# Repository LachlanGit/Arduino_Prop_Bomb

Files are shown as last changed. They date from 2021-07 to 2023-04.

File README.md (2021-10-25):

# Arduino Prop Bomb
Prop bomb for use in Airsoft/Gel ball/Nerf games

[Check out the video here](https://youtu.be/Dwf5lzY_378)

Submit issues via the issues tab. Contact me at lachlan.github@outlook.com

## Electronics parts list: 
(It may be possible to use alternative parts, however, the code will have to be customised for them)
- Arduino Mega 2560
- 12 button keypad (0-9, *, #)
- 128 * 64 3-wire SPI LCD display (I used [this](https://www.digikey.com.au/product-detail/en/dfrobot/DFR0091/DFR0091-ND/7597123) one)
- Red and green buttons either with built in LED's or separate LED's (Make sure to use the appropriate resistor for your LED's)
- 3 position 2 pole keyswitch if using for power and to enter config mode **or** 2 position 1 pole switch if just for config mode (Use a separate switch for power)
- Square wave buzzer
- 7 to 12 volt power supply for Arduino (in my case, I used 2 18650 Li-Ion cells in series in battery holders)
- BMS to prevent over charging/over discharging of batteries (important if using Li-Po or Li-Ion batteries without integrated BMS)
- Various jumper cables/ribbon cables to connect everything together

## Optional parts list: 
- Some kind of case or enclosure (I used a black ABS 197Lx112Wx63Hmm box)
- Protective acrylic cover for LCD
- Charging PCB for Li-ion or Li-po batteries (I have omitted this and just remove the batteries when I need to charge them)
- Handle for carrying
- Protective corners to prevent damage to the bomb

## Wiring connections: 
*NO = Normally open, NC = Normally closed*

*These can be edited in the "Pins" section of the code*

1. SPI LCD Display
    1. LCD VCC - Arduino 5V
    2. LCD GND - Arduino GND
    3. LCD RS - Arduino 4
    4. LCD RW - Arduino 3
    5. LCD E - Arduino 2

2. Keypad
    1. Keypad 2 - Arduino 20
    2. Keypad 3 - Arduino 19
    3. Keypad 4 - Arduino 18
    4. Keypad 5 - Arduino 17
    5. Keypad 6 - Arduino 16
    6. Keypad 7 - Arduino 15
    7. Keypad 8 - Arduino 14

*Pinout on my keypad* Image of keypad pinout

3. Buttons
    1. Red button COM - Arduino GND (Or use 49 to save on wiring)
    2. Red button NO - Arduino 47
    3. Green button COM - Arduino GND (Or use 46 to save on wiring)
    4. Green button NO - Arduino 48

4. LED's
    1. Red LED Cathode (-) - Arduino GND
    2. Red LED Anode (+) - Arduino 53 (Must use appropriate resistor)
    3. Green LED Cathode (-) - Arduino GND
    4. Green LED Anode (+) - Arduino 52 (Must use appropriate resistor)

5. Keyswitch
    1. Key GND - Arduino GND (Or use 24 to save on wiring)
    2. Key NO - Arduino 22

6. Buzzer
    1. Buzzer - Arduino 11 + 12 (Polarity irrelevant)

7. Battery (Use second pole of keyswitch **or** a separate switch in series to toggle power)
    1. Battery Ground (-) - Arduino GND
    2. Battery Positive (+) - Arduino VIN

## Required libraries
- U8g2 by oliver (Available in library manager or [here](https://github.com/olikraus/u8g2))
- Keypad by Community https://github.com/Chris--A/Keypad (Available in library manager or [here](https://github.com/Chris--A/Keypad))
- Button by t3db0t (Available [here](https://github.com/virgildisgr4ce/Button))
- ToneAC by Tim Eckel (Available in library manager or [here](https://github.com/teckel12/arduino-toneac))
- EEPROMEx by Thijs Elenbaas (Available in library manager or [here](http://playground.arduino.cc/Code/EEPROMex))
- Timers by LachlanGit/Me (Available [here](https://github.com/LachlanGit/Arduino_Timer_Library))

## Configuration mode usage
- Turn key to config position (will be different depending on your key switch used)
- Use Red and Green buttons to cycle through screens
- Type in setting with numbers, taking note of the unit used (milliseconds/seconds/etc.)
- Press "#" to save the setting to EEPROM, or press "\*" to clear entered value
- Turn key out of config position to go back to play mode

## Game play usage
- Use [this video](https://youtu.be/Dwf5lzY_378) as a rough guide or follow on-screen instructions

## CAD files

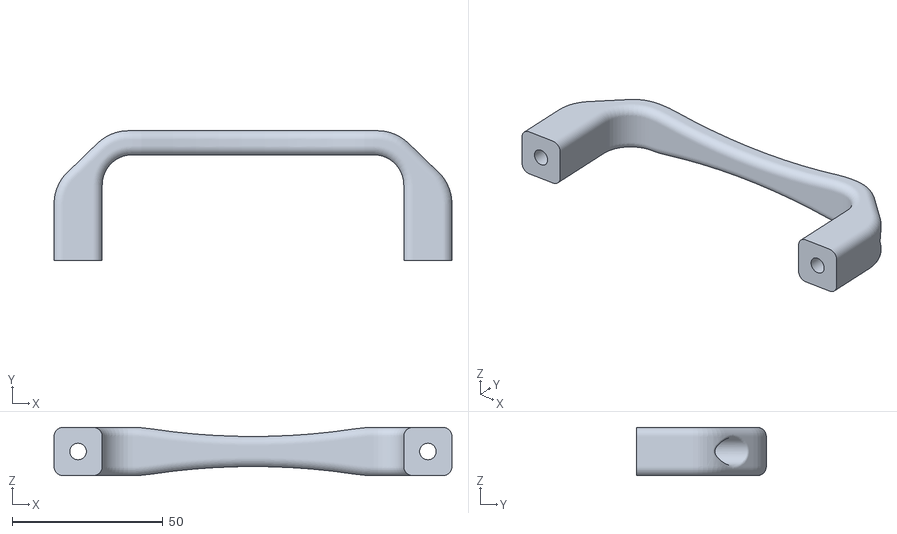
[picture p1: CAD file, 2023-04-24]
3D Print Files/Box handle.STL
132.0 x 43.0 x 16.0

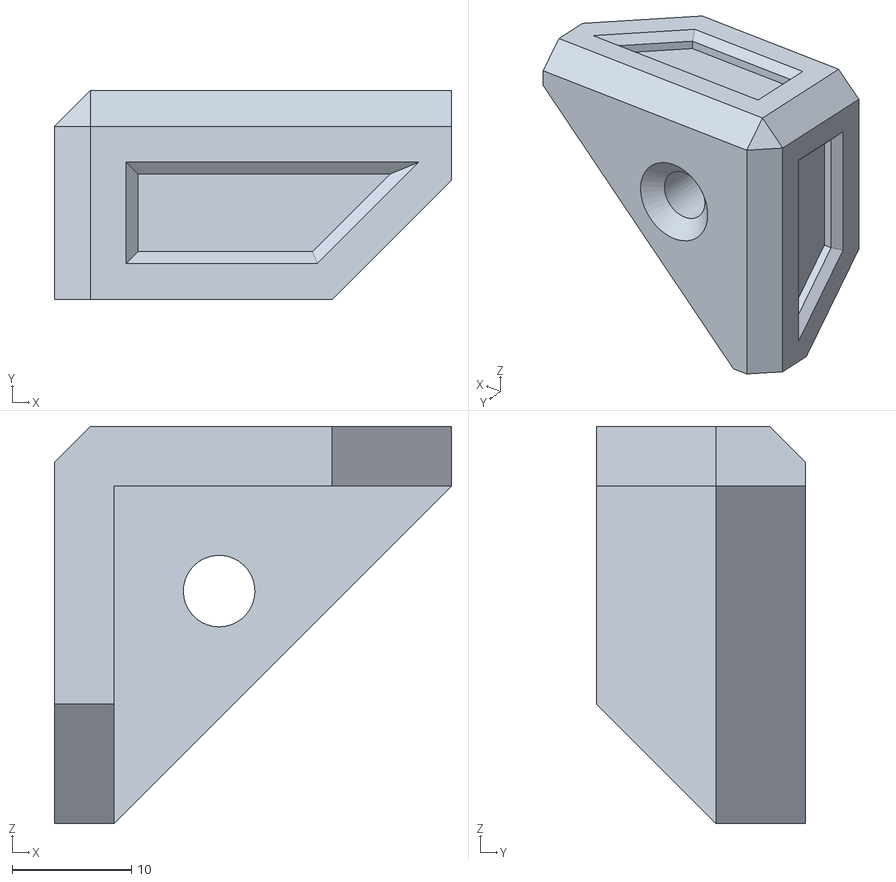
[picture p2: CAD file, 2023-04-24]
3D Print Files/Box corners top.STL
33.3 x 17.5 x 33.3

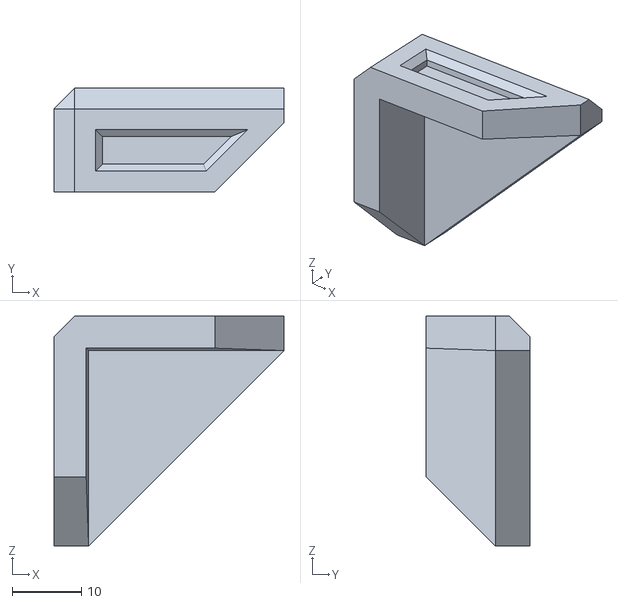
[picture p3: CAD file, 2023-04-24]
3D Print Files/Box corners bottom.STL
33.3 x 15.0 x 33.3

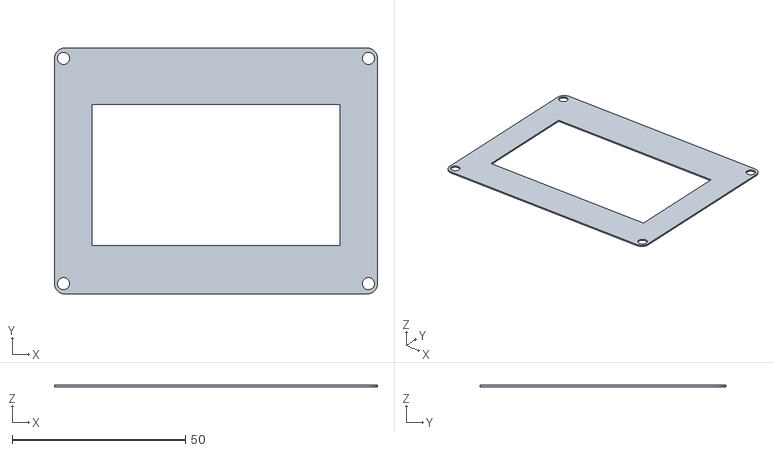
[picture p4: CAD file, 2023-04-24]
3D Print Files/Screen cutout.STL
93.2 x 71.0 x 0.5

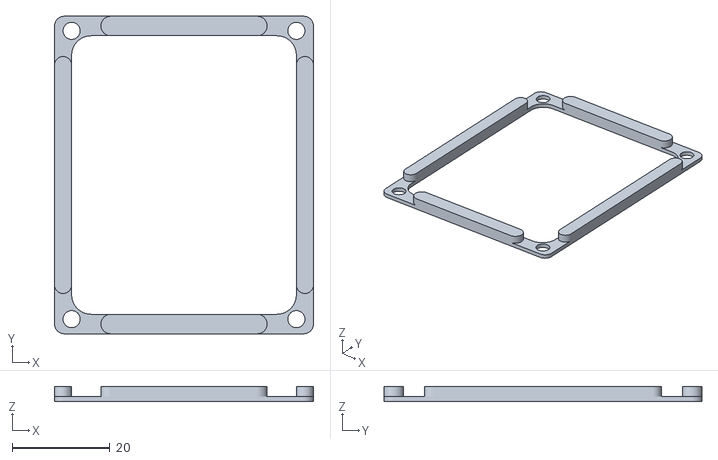
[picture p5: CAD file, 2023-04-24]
3D Print Files/Keypad frame.STL
53.0 x 65.0 x 3.00

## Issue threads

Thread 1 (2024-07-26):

Issue with LCD on this

AMAN798, 2024-07-26:
I am trying to make a prop for a Paintball game this sunday and have been trying to use your code, Have an issue of the LCD not working (Stays blank or random characters it is a Jaycar 128x64 LCD) just seeing if you be able to offer any assistance.

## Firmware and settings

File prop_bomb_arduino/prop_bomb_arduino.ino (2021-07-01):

/*
  Downloaded from and more information at: https://github.com/LachlanGit/Arduino_Prop_Bomb
  
  Code to run on prop bomb for use in airsoft/gel-blaster/nerf games
  Requires:
  - Arduino Mega2560
  - 128 x 64 SPI Monochrome LCD display
  - 3 x 4 Numerical keypad
  - Red + Green button
  - Red + Green LED or LED's in buttons
  - 3 position keyswitch (Off, On, Config) or 2 position keyswitch (normal, config) with seperate power toggle switch
  - Square wave buzzer
*/

//===== Libraries =====
#include <U8g2lib.h>

#include <Key.h>
#include <Keypad.h>

#include <Button.h>

#include <toneAC.h>

#include <EEPROMex.h>
#include <EEPROMVar.h>

#include <Timers.h>



//===== Other includes =====
#include "fonts.h"



//===== Pins =====
//Buttons
#define RBUTTON 47
#define RBUTTONGND 49
#define GBUTTON 48
#define GBUTTONGND 46
#define RLED 53
#define GLED 52

//Key switch
#define KEYNO 22
#define KEYGND 24

//Keypad
#define KEY1 19 //3 ON KEYPAD BOARD
#define KEY2 14 //8
#define KEY3 15 //7
#define KEY4 17 //5
#define KEYA 18 //4
#define KEYB 20 //2
#define KEYC 16 //6

//LCD
#define LCD_E 2
#define LCD_RW 3
#define LCD_RS 4

//Buzzer
//11 + 12



//===== Keypad Layout =====
#define KEYPAD_ROWS 4
#define KEYPAD_COLS 3
const char keys[KEYPAD_ROWS][KEYPAD_COLS] = {
  {'1', '2', '3'},
  {'4', '5', '6'},
  {'7', '8', '9'},
  {'*', '0', '#'}
};
const byte rowPins[KEYPAD_ROWS] = {KEY1, KEY2, KEY3, KEY4};
const byte colPins[KEYPAD_COLS] = {KEYA, KEYB, KEYC};
Keypad keypad = Keypad(makeKeymap(keys), rowPins, colPins, KEYPAD_ROWS, KEYPAD_COLS);



//===== Main states =====
#define SND 0                  //Search and destroy
#define DOM 1                  //Domination
#define CONFIG 2               //Config mode



//===== Button objects =====
Button redButton = Button(RBUTTON, BUTTON_PULLUP_INTERNAL, true, 50);
Button greenButton = Button(GBUTTON, BUTTON_PULLUP_INTERNAL, true, 50);



//===== Timer objects =====
Timer sndPrimingTimer(0, true);
Timer sndCodeDispTimer(0, true);
Timer sndCodeResultTimer(0, true);
Timer sndCountdownTimer(0, true);



//===== LCD Object =====
U8G2_ST7920_128X64_F_SW_SPI u8g2(U8G2_R0, /* SCK/E=*/ LCD_E, /* SID/RW=*/ LCD_RW, /* CS/RS=*/ LCD_RS, /* reset=*/ U8X8_PIN_NONE);



//===== Configurable settings =====
//These will be over-ridden with values in EEPROM on startup
//Holding both buttons on startup will revert to the default values entered below:

//Global settings
byte stateMain = 0; //0: SND, 1: DOM                (Default: 0 (SND))
byte volume = 10; //0 (off) to 10 (max)             (Default: 10)

//SND
long sndPrimingTime = 3000; //millis                (Default: 3 seconds)
byte sndCodeLength = 6; //Ranges from 3 to 8        (Default: 6 digits)
int sndCodeDisplayTime = 0; //millis (0 for auto)   (Default: 0 (auto))
long sndCountdownTime = 90000; //millis             (Default: 1m30s)
bool sndPenaltyMode = false; //true = on            (Default: Penalty off)
long sndPenaltyApplied = 10000; //millis            (Default: 10s)

//DOM
long domPrimingTime = 10000; //millis               (Default: 10 seconds)
long domCountdownTime = 120000; //millis            (Default: 2m00s)



//===== EEPROM Addresses =====
int addStateMain;
int addVolume;
int addSndPrimingTime;
int addSndCodeLength;
int addSndCodeDisplayTime;
int addSndCountdownTime;
int addSndPenaltyMode;
int addSndPenaltyApplied;
int addDomPrimingTime;
int addDomCountdownTime;



//===== Random seed generation =====
volatile uint32_t seed;  // These two variables can be reused in your program after the
volatile int8_t nrot;    // function CreateTrulyRandomSeed()executes in the setup() function.



//===== Setup =====
void setup() {
  Serial.begin(119200);

  //Generate random seed
  CreateTrulyRandomSeed();
  randomSeed(seed);


  //Set-up pins
  pinMode(KEYNO, INPUT_PULLUP); //GND->COM Pin22->NO, 1 means locked, 0 means unlocked
  pinMode(KEYGND, OUTPUT);
  pinMode(RBUTTON, INPUT_PULLUP); //GND->switch Pin23->switch, 0 means pressed
  pinMode(GBUTTON, INPUT_PULLUP); //GND->switch Pin24->switch, 0 means pressed
  pinMode(RBUTTONGND, OUTPUT);
  pinMode(GBUTTONGND, OUTPUT);

  digitalWrite(KEYGND, LOW);
  digitalWrite(RBUTTONGND, LOW);
  digitalWrite(GBUTTONGND, LOW);

  pinMode(RLED, OUTPUT);
  pinMode(GLED, OUTPUT);


  //LCD setup
  u8g2.begin();
  resetFont();


  //Keypad setup
  keypad.setDebounceTime(1);


  //EEPROM setup
  setupEEPROM();


  //Calculate automatic code display length if set to 0
  if (sndCodeDisplayTime == 0) {
    sndCodeDisplayTime = 100 + sndCodeLength * 250;
  }
}



//===== Main loop =====
void loop() {
  resetFont();
  u8g2.clearBuffer();


  //Check key state
  if (!digitalRead(KEYNO)) {
    stateMain = CONFIG;
    digitalWrite(RLED, LOW);
    digitalWrite(GLED, LOW);
  }


  //Run code relevant to set mode
  switch (stateMain) {
    case SND:
      {
        mode_snd();
      }
      break;

    case DOM:
      {
        mode_dom();
      }
      break;

    case CONFIG:
      {
        mode_config();
      }
      break;
  }


  u8g2.sendBuffer();
}

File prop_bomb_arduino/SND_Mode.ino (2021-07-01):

//===== SND States =====
#define SND_IDLE 0
#define SND_CODE_DISP 1
#define SND_CODE_ENTRY 2
#define SND_COUNTDOWN 3
#define SND_END 4


byte stateSnd = SND_IDLE;
bool stateArm = false;



//===== Fixed settings =====
const unsigned long codeConfirmTime = 1500;



//===== Code generation =====
int generatedCode[8];
char generatedCodeChar[8 + 1];



//===== Code entry =====
#define CODE_WAITING 0
#define CODE_CORRECT 1
#define CODE_WRONG 2
byte codeEntryResult = CODE_WAITING;

char customKey;
bool wrongCode;
char enteredCodeStr[9];
int cursorPos;



//===== Sound effect states =====
bool powerEffectPlayed = false;
bool sndSirenPlayed = false;
bool victoryPlayed = false;



//===== Main loop =====
void mode_snd() {
  u8g2.drawRFrame(0, 0, 128, 64, 5);

  switch (stateSnd) {
    case SND_IDLE:
      {
        if (!digitalRead(RBUTTON) && !digitalRead(GBUTTON)) {
          primingLoadScreen();
        } else {
          sndPrimingTimer.setLength(sndPrimingTime);

          drawStrMiddle(0, 12, 128, "READY TO ARM");
          drawStrMiddle(0, 36, 128, "<HOLD BOTH BUTTONS>");

          toneAC();
          digitalWrite(RLED, flashState(500));
          digitalWrite(GLED, flashState(500));
        }
      }
      break;



    case SND_CODE_DISP:
      {
        sndCodeDispTimer.start();

        codeDisplay();

        if (sndCodeDispTimer.timeLeft() < 0) {
          codeEntryResult = CODE_WAITING;

          sndCodeResultTimer.pause();
          sndCodeResultTimer.setLength(1500);

          stateSnd = SND_CODE_ENTRY;
          cursorPos = 0;
        }
      }
      break;



    case SND_CODE_ENTRY:
      {
        if (stateArm) {
          sndCountdown(true);
        }

        switch (codeEntryResult) {
          case CODE_WAITING:
            {
              codeEntry();
            }
            break;

          case CODE_WRONG:
            {
              sndCodeResultTimer.start();

              digitalWrite(RLED, flashState(250));
              digitalWrite(GLED, !flashState(250));

              drawStrMiddle(0, 12, 128, "ERROR:");
              drawStrMiddle(0, 45, 128, "WRONG CODE!");

              u8g2.setFont(u8g2_font_unifont_t_0_77);
              drawGlyphMiddle(0, 32, 128, 9888);
              resetFont();

              if (sndCodeResultTimer.timeLeft() < 0) {
                sndPrimingTimer.setLength(sndPrimingTime);

                if (stateArm) {
                  stateSnd = SND_COUNTDOWN;
                } else {
                  stateSnd = SND_IDLE;
                }
              }
            }
            break;

          case CODE_CORRECT:
            {
              sndCodeResultTimer.start();

              digitalWrite(RLED, LOW);
              digitalWrite(GLED, LOW);

              drawStrMiddle(0, 12, 128, "CORRECT CODE");

              if (stateArm) {
                sndCountdownTimer.pause();

                drawStrMiddle(0, 36, 128, "DISARMED");

                if (!powerEffectPlayed) {
                  u8g2.sendBuffer();
                  beepPowerDown();
                  powerEffectPlayed = true;
                }
              } else {
                drawStrMiddle(0, 36, 128, "ARMED");

                if (!powerEffectPlayed) {
                  u8g2.sendBuffer();
                  beepPowerUp();
                  powerEffectPlayed = true;
                }
              }

              if (sndCodeResultTimer.timeLeft() < 0) {
                sndPrimingTimer.setLength(sndPrimingTime);
                
                if (stateArm) {
                  stateSnd = SND_END;
                  stateArm = false;
                } else {
                  stateSnd = SND_COUNTDOWN;
                  stateArm = true;

                  sndCountdownTimer.setLength(sndCountdownTime);
                  sndCountdownTimer.start();
                }
              }
            }
            break;
        }
      }
      break;



    case SND_COUNTDOWN:
      {
        if (!digitalRead(RBUTTON) && !digitalRead(GBUTTON)) {
          primingLoadScreen();
        } else {
          sndCountdown(false);

          sndPrimingTimer.setLength(sndPrimingTime);
        }
      }
      break;



    case SND_END:
      {
        drawStrMiddle(0, 53, 128, "PRESS BOTH BUTTONS");
        drawStrMiddle(0, 64, 128, "TO RESET");

        if (stateArm) {
          drawStrMiddle(0, 12, 128, "BOMB EXPLODED!");
          drawStrMiddle(0, 23, 128, "T's WIN!");

          if (!sndSirenPlayed) {
            u8g2.sendBuffer();
            beepSiren();
            sndSirenPlayed = true;
          }
        } else {
          drawStrMiddle(0, 12, 128, "DEFUSED");
          drawStrMiddle(0, 23, 128, "CT's WIN!");

          if (!victoryPlayed) {
            u8g2.sendBuffer();
            beepVictory();
            victoryPlayed = true;
          }
        }

        digitalWrite(RLED, flashState(500));
        digitalWrite(GLED, flashState(500));

        if (redButton.isPressed() && greenButton.isPressed()) {
          stateSnd = IDLE;
          stateArm = false;

          victoryPlayed = false;
          sndSirenPlayed = false;
          while (redButton.isPressed() && greenButton.isPressed());
        }
      }
      break;
  }
}



//===== Priming screen for SND =====
void primingLoadScreen() {
  sndPrimingTimer.start();

  digitalWrite(RLED, HIGH);
  digitalWrite(GLED, HIGH);

  if (!stateArm) {
    drawStrMiddle(0, 12, 128, "ARMING");
  } else {
    drawStrMiddle(0, 12, 128, "DISARMING");
    sndCountdown(true);
  }

  float loadingBarProgress = 1 - (sndPrimingTimer.timeLeft() / float(sndPrimingTime));
  u8g2.drawFrame(4, 27, 120, 10);
  u8g2.drawBox(4, 27, 120 * loadingBarProgress, 10);

  primingBeep(sndPrimingTimer.timeLeft(), sndPrimingTime);

  if (sndPrimingTimer.timeLeft() < 0) {
    stateSnd = SND_CODE_DISP;
    sndCodeDispTimer.setLength(sndCodeDisplayTime);
    generateCode();

    digitalWrite(RLED, LOW);
    digitalWrite(GLED, LOW);

    toneAC();
  }
}



//===== Generate code =====
void generateCode() {
  for (int i = 0; i < sndCodeLength; i++) {
    generatedCode[i] = random(0, 10);
    generatedCodeChar[i] = generatedCode[i] + 48;
  }
}



//===== Display generated code =====
void codeDisplay() {
  u8g2.drawStr(47, 12, "CODE:");
  u8g2.setFont(u8g2_font_dseg14_cr);
  u8g2.setFontMode(1);
  u8g2.setDrawColor(1);
  drawStrMiddle(0, 42, 128, generatedCodeChar);
  resetFont();

  if (stateArm) {
    sndCountdown(true);
  }
}
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
